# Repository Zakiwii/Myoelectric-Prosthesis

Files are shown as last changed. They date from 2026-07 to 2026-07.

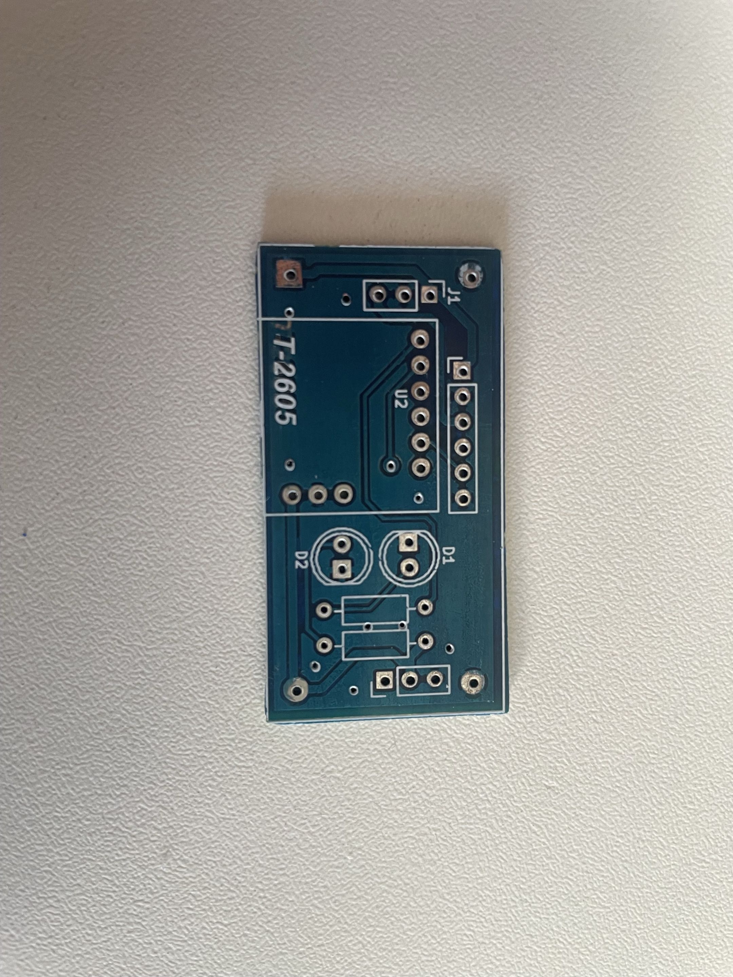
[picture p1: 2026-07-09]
PCB front irl.jpg

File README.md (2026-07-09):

[README.md](https://github.com/user-attachments/files/29821908/README.md)
# EMG Myoelectric Prosthesis

A myoelectric wrist/hand prosthesis controlled by EMG (electromyography) signals, developed as a Master's thesis (PFE) project at USTHB (Université des Sciences et de la Technologie Houari Boumediene), Algiers.

> 🎓 Defended with highest honors (*mention très bien*).

Prototype
<!-- Replace the line above with your own image path once uploaded, or add more images below -->

## Overview

This project implements a low-cost, functional prosthetic wrist that translates forearm EMG muscle signals into automated wrist movements via a servo-driven mechanism. The goal was to build an accessible, reproducible design using widely available components rather than expensive commercial EMG modules.

## How It Works

1. An EMG sensor module picks up electrical activity from the forearm muscles (bipolar signal, powered by a symmetric ±9V supply).
2. The raw signal is conditioned and thresholded to detect muscle contraction events.
3. A Digispark ATtiny85 microcontroller reads the processed signal and generates a manual PWM control signal.
4. An MG996R servo motor executes the corresponding wrist movement.
5. Power is regulated through an LM2596 buck converter for stable operation.

## Hardware

- **Microcontroller:** Digispark ATtiny85
- **EMG sensing:** EMG module (MyoWare-style), symmetric ±9V supply
- **Actuation:** MG996R servo motor
- **Power regulation:** LM2596 buck converter
- **PCB:** Custom-designed in KiCad (schematic capture, DRC, ground planes, Gerber export)
- **Enclosure:** 3D-modeled in Fusion 360, 3D-printed

## Repository Structure

```
prothese-emg/
├── hardware/
│   ├── kicad/          # Schematic, PCB layout, Gerber files
│   └── enclosure/      # Fusion 360 / STEP / STL files
├── firmware/
│   └── attiny85/        # C/C++ firmware for the ATtiny85
├── docs/
│   ├── thesis.pdf        # Full thesis document (French)
│   └── diagrams/         # System architecture diagrams
└── media/
    └── photos, demo video
```

## Firmware

Written in C/C++ for the ATtiny85 (Digispark board), including manual PWM generation for servo control and EMG signal threshold calibration logic.

## Skills & Tools Used

`KiCad` · `Fusion 360` · `Arduino IDE / Micronucleus` · `C/C++` · `EMG signal processing` · `PCB design (DRC, Gerber export)`

## Author

**Senouci Abderraouf Zaki** — M2 Electronics and Embedded Systems, USTHB.

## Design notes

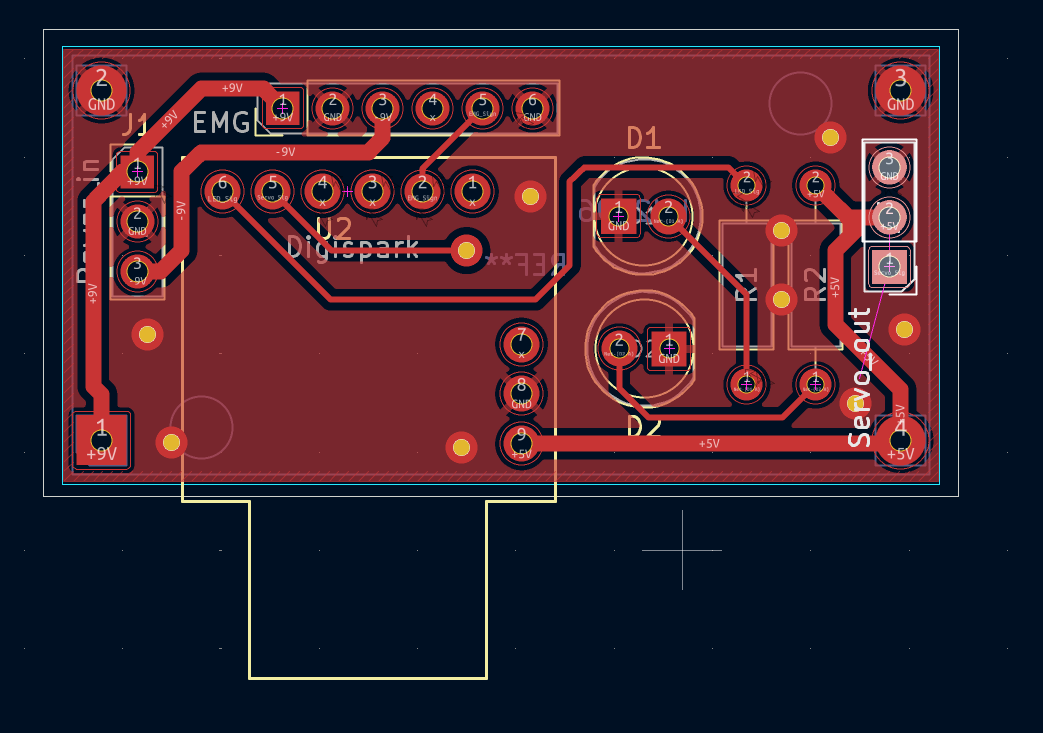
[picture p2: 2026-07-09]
PCB top.png

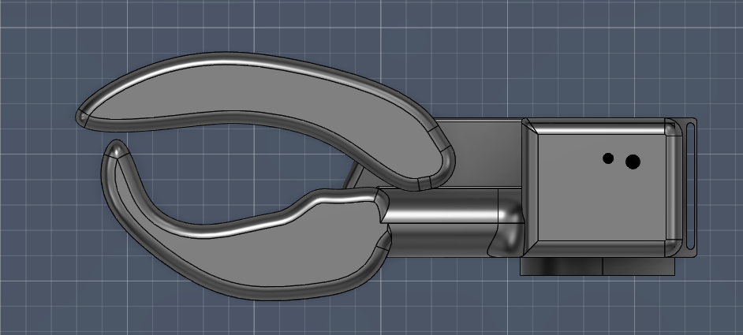
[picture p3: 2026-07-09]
pince fermée.png

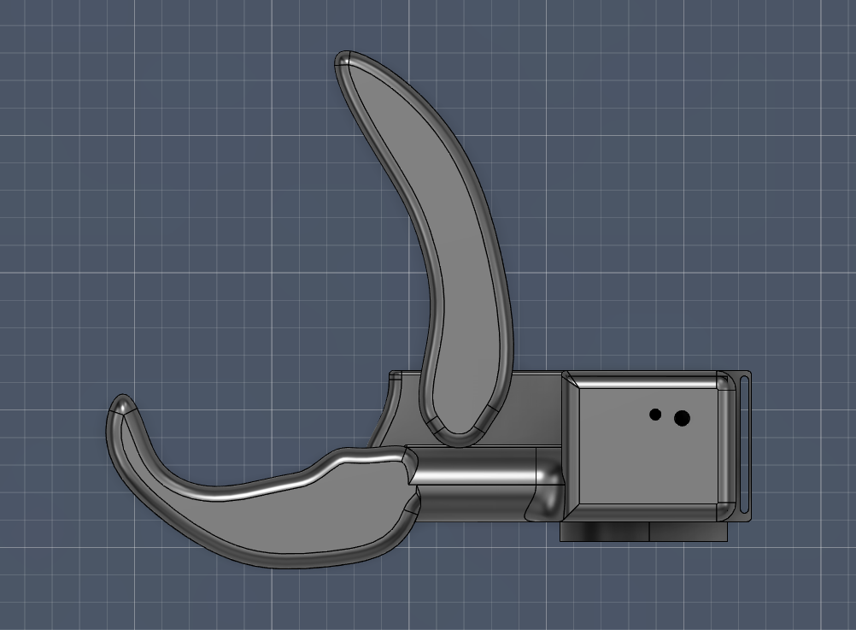
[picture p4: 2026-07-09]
pince ouverte.png

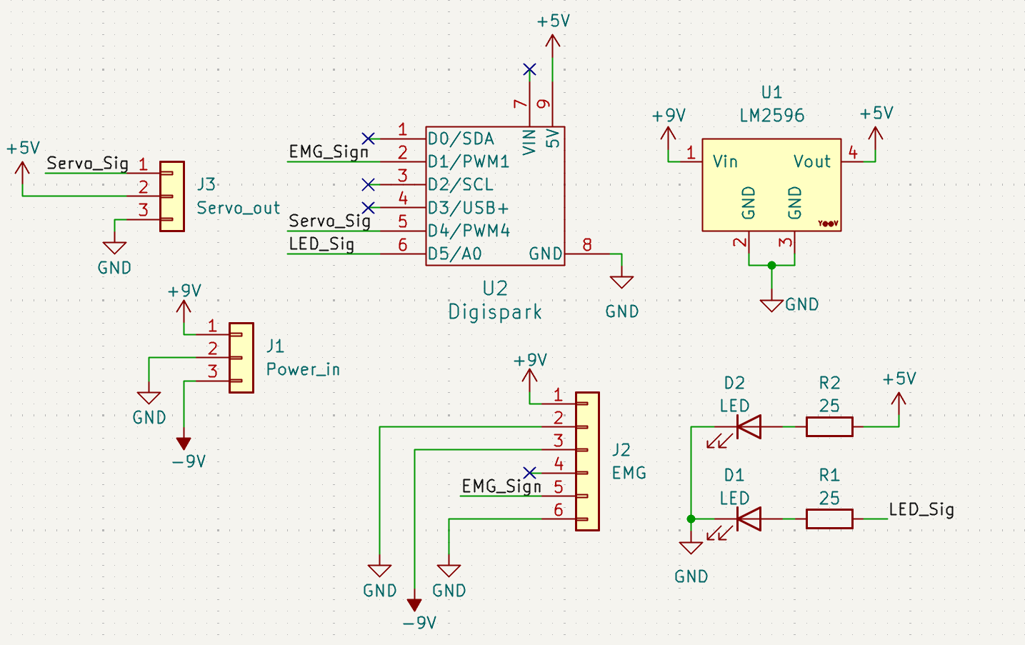
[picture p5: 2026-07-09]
Circuit.png

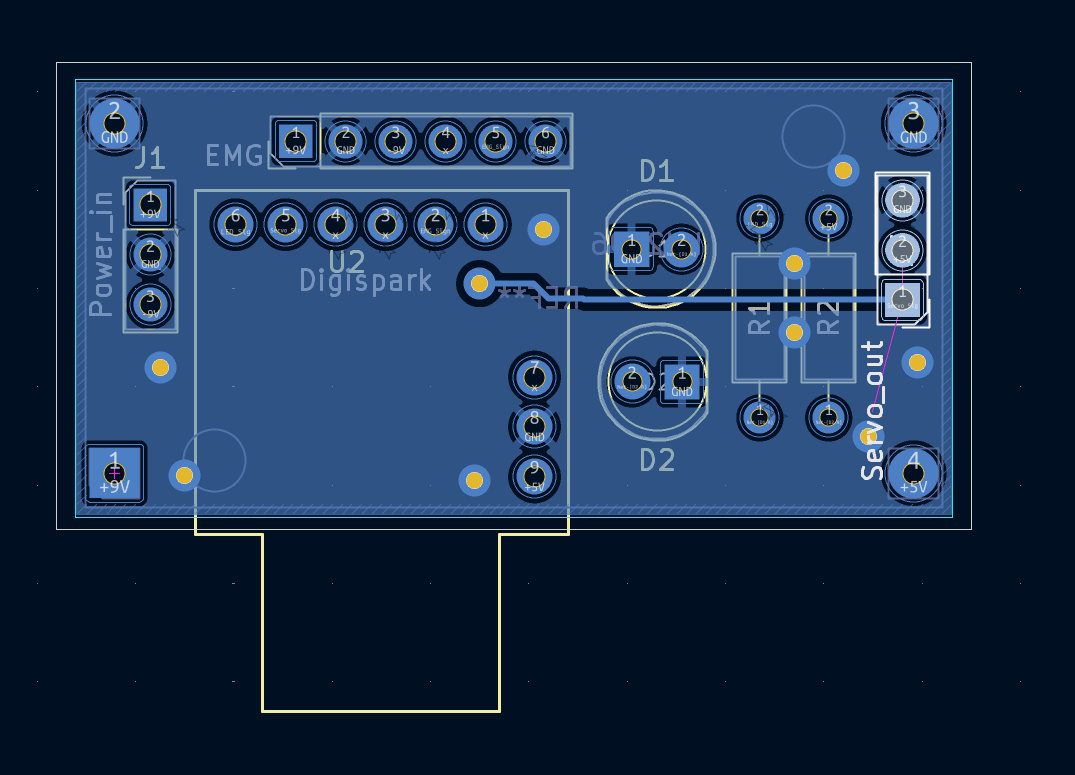
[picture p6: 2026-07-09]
PCB bottom.png

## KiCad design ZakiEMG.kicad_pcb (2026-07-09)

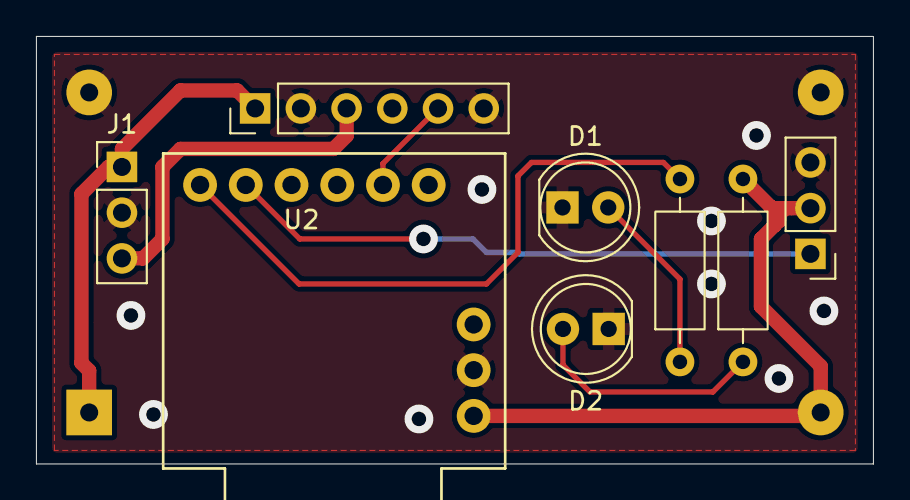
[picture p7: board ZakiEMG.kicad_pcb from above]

Board: 2 copper layers, 46.5 x 23.8 mm, 9 parts (1 on the bottom side), 9 nets.

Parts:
D1, D2: LED; LED_D5.0mm
J1: Power_in; PinHeader_1x03_P2.54mm_Vertical
J2: EMG; PinHeader_1x06_P2.54mm_Vertical
J3: Servo_out; PinHeader_1x03_P2.54mm_Vertical
R1, R2: 25; R_Axial_DIN0207_L6.3mm_D2.5mm_P10.16mm_Horizontal
U1: LM2596; YAAJ_DCDC_StepDown_LM2596
U2: Digispark

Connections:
+5V: J3.2, R2.2, U1.4 (Vout), U2.9 (5V)
+9V: J1.1, J2.1, U1.1 (Vin)
-9V: J1.3, J2.3
/EMG_Sign: J2.5, U2.2 (D1/PWM1)
/LED_Sig: R1.2, U2.6 (D5/A0)
/Servo_Sig: J3.1, U2.5 (D4/PWM4)
GND: D1.1 (K), D2.1 (K), J1.2, J2.2, J2.6, J3.3, U1.2 (GND), U1.3 (GND), U2.8 (GND)
unnamed: D1.2 (A), R1.1
unnamed: D2.2 (A), R2.1
